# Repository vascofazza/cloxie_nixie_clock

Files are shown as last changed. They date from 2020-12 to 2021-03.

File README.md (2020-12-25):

# Cloxie

Schematics and code for Cloxie: my Nixie Tube Clock.




The circuit and custom PCB are designed around the popular IN-14 Nixie tubes.

You can find the schematics here: https://github.com/vascofazza/cloxie_nixie_clock/blob/main/nixie_board/schematics.pdf

Watch the clock in action: https://www.youtube.com/watch?v=ZD35oEGX9IY

## Features

- NTP time sync over Wi-Fi
- The tubes are dimmable via PWM
- 6 RGB leds under the tubes with configurable patterns
- Automatic brightness control with a photoresistor
- Configurable via an onboard web server (reachable on the local network at: http://cloxie.local)
- Configurable via a dedicated Android App (available here: https://github.com/vascofazza/Cloxie-connect)
- Optional temperature sensor
- Alarm/Timer/StopWatch functionalities

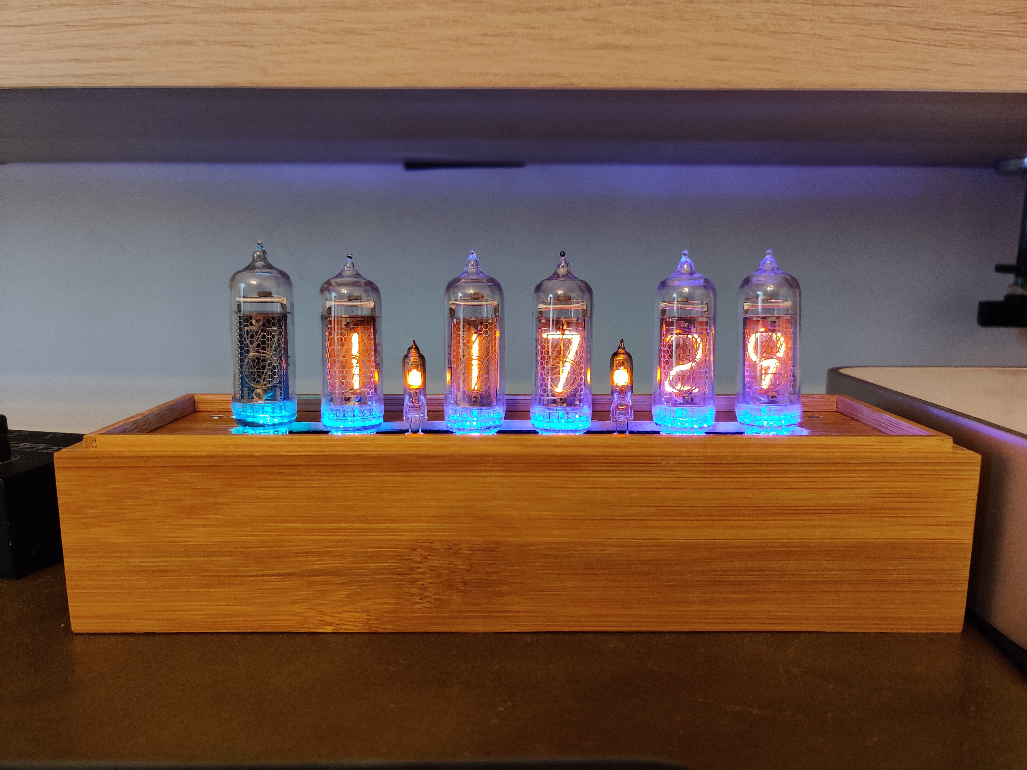
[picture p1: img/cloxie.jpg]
cloxie nixie clock


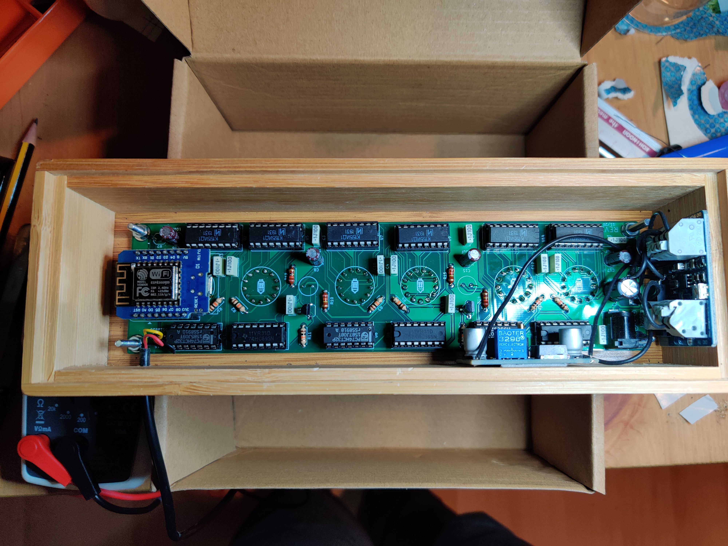
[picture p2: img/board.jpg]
cloxie board


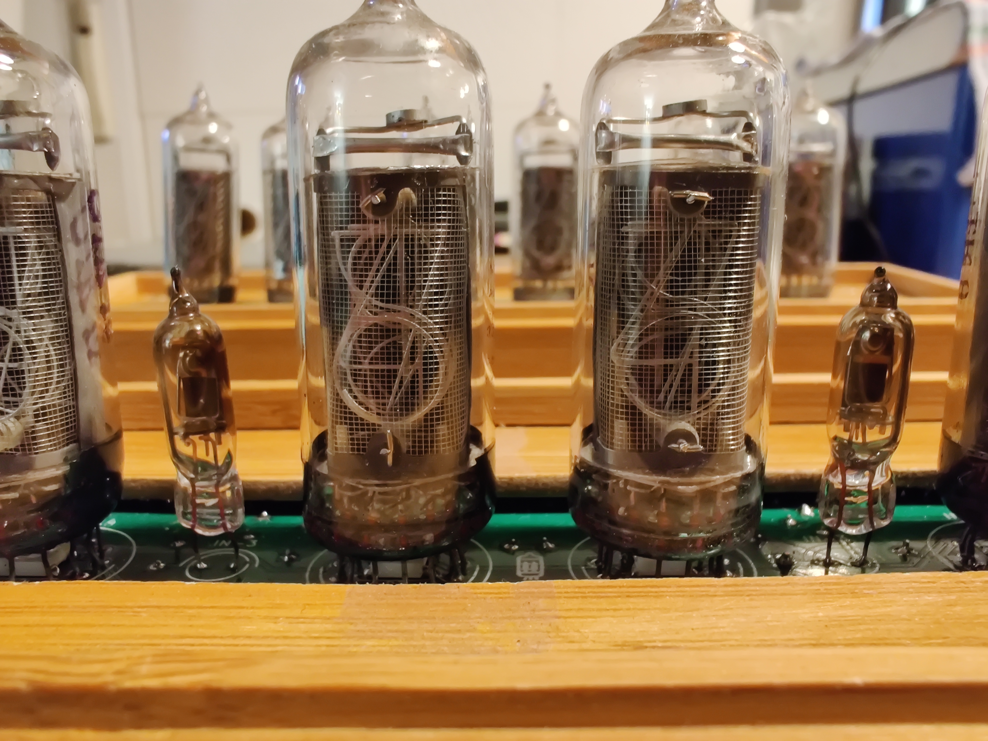
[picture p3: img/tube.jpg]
nixie tube


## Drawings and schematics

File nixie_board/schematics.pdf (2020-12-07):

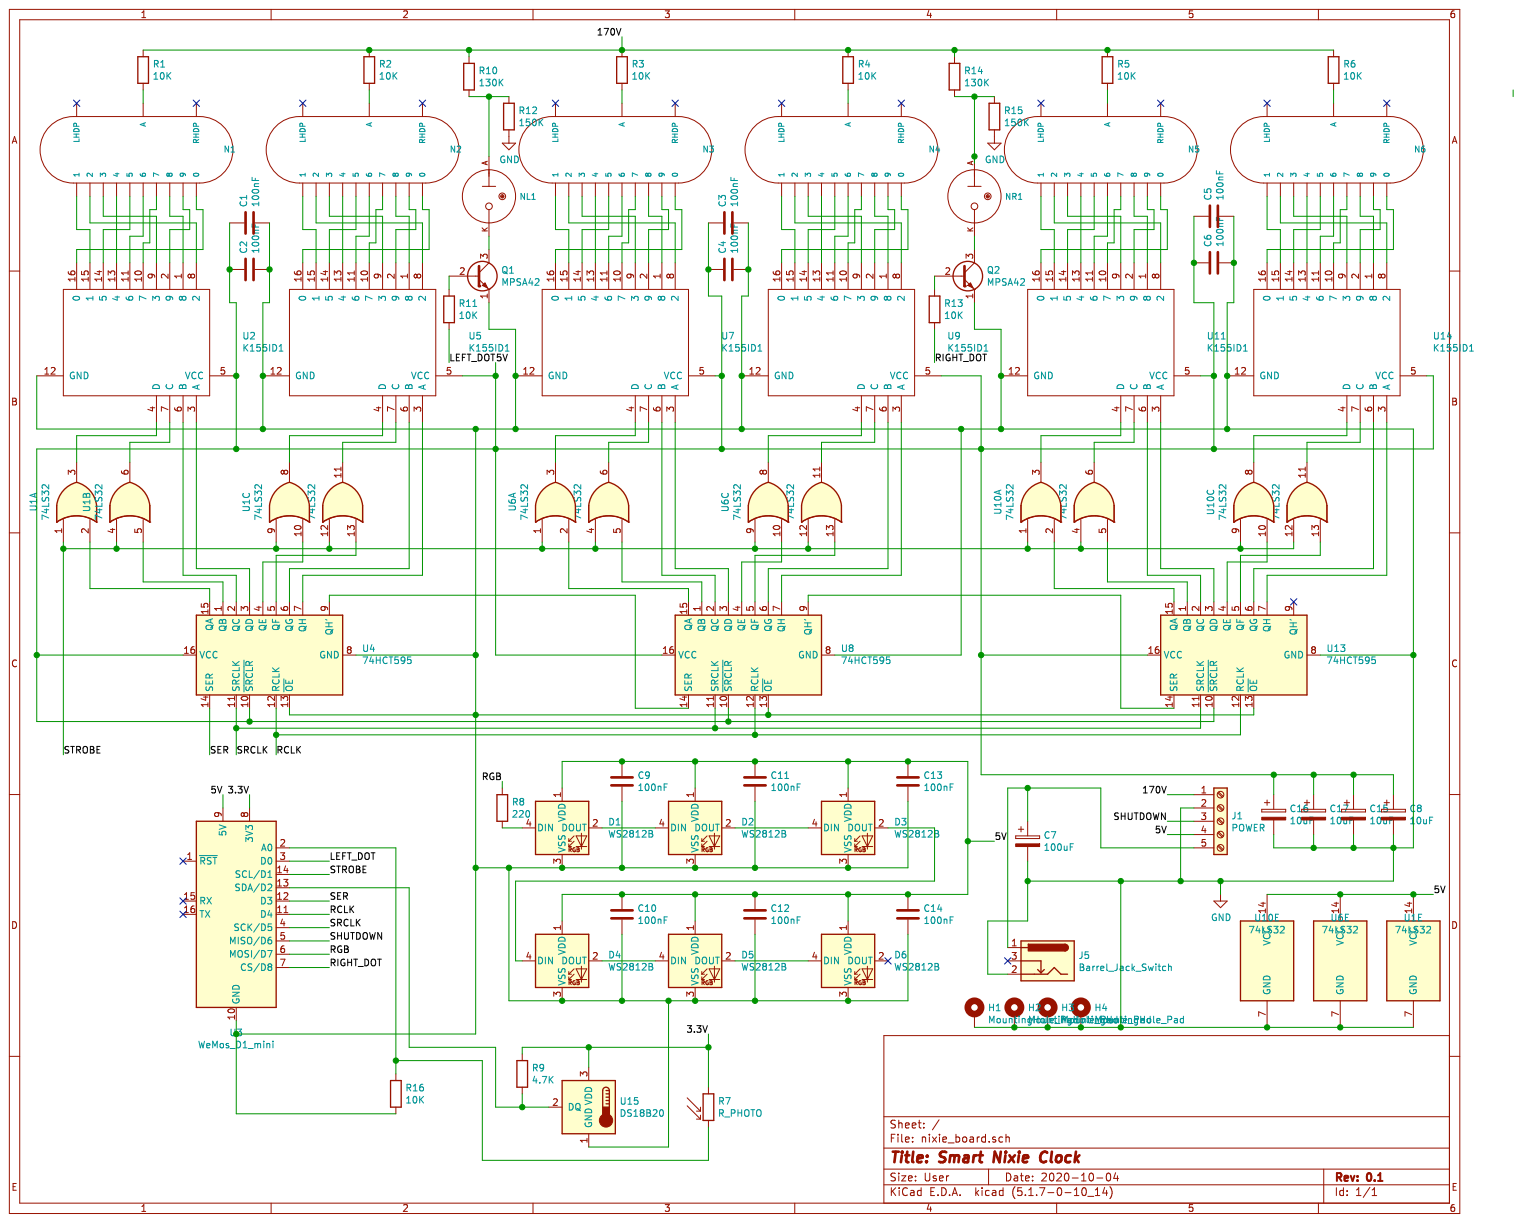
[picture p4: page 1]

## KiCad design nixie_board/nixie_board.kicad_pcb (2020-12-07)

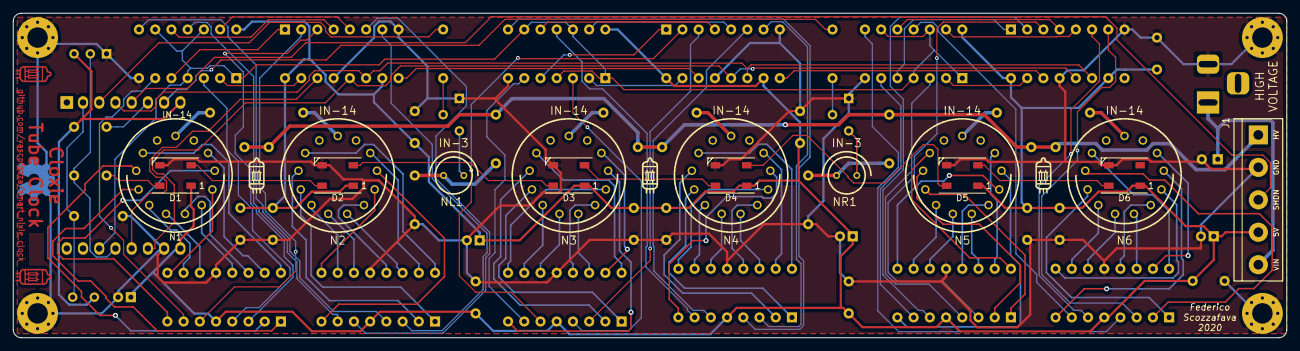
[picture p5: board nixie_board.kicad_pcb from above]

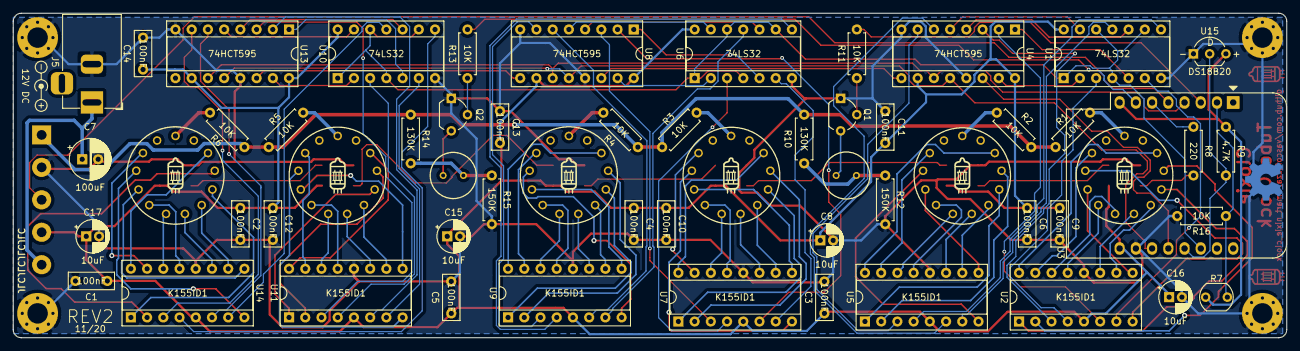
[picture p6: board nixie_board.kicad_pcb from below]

Board: 2 copper layers, 199.4 x 50.8 mm, 85 parts (59 on the bottom side), 131 nets.

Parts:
C1, C2, C3, C4, C5, C6, C9, C10, C11, C12, C13, C14: 100nF; C_Disc_D7.0mm_W2.5mm_P5.00mm
C7: 100uF; CP_Radial_D6.3mm_P2.50mm
C8, C15, C16, C17: 10uF; CP_Radial_D5.0mm_P2.00mm
D1, D2, D3, D4, D5, D6: WS2812B; LED_WS2812B_PLCC4_5.0x5.0mm_P3.2mm
H1, H2, H3, H4: MountingHole_Pad; MountingHole_3.2mm_M3_Pad_Via
J1: POWER; TerminalBlock_bornier-5_P5.08mm
J5: Barrel_Jack_Switch; BarrelJack_Horizontal
N1, N2, N3, N4, N5, N6: IN-14; nixies-us-IN-14
NL1: IN-3; nixies-us-IN-3
NR1: IN-3; nixies-us-IN-3
Q1, Q2: MPSA42; TO-92_Wide
R1, R2, R3, R4, R5, R6, R11, R13, R16: 10K; R_Axial_DIN0207_L6.3mm_D2.5mm_P7.62mm_Horizontal
R7: R_PHOTO; R_LDR_5.1x4.3mm_P3.4mm_Vertical
R8: 220; R_Axial_DIN0207_L6.3mm_D2.5mm_P7.62mm_Horizontal
R9: 4.7K; R_Axial_DIN0207_L6.3mm_D2.5mm_P7.62mm_Horizontal
R10, R14: 130K; R_Axial_DIN0207_L6.3mm_D2.5mm_P7.62mm_Horizontal
R12, R15: 150K; R_Axial_DIN0207_L6.3mm_D2.5mm_P7.62mm_Horizontal
S1: Symbol_Barrel_Polarity
S2, S2b: OSHW-Symbol_6.7x6mm_Copper
S4, S5: LOGO; tube
S6, S7, S8, S9, S10, S11, S12, S13, S15, S16, S17: LOGO; tube_silk
U1, U6, U10: 74LS32; DIP-14_W7.62mm_Socket
U2, U5, U7, U9, U11, U14: K155ID1; DIP-16_W7.62mm_Socket
U3: WeMos_D1_mini; WEMOS_D1_mini_light
U4, U8, U13: 74HCT595; DIP-16_W7.62mm_Socket
U15: DS18B20; TO-92_Inline_Wide

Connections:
/3.3V: R7.1, R9.1, U3.8, U15.3
/5V: C1.1, C2.1, C3.1, C4.1, C5.1, C6.1, C8.1, C9.1, C10.1, C11.1, C12.1, C13.1, C14.1, C15.1, C16.1, C17.1, D1.1, D2.1, D3.1, D4.1, D5.1, D6.1, J1.4, U1.14, U2.5, U3.9, U4.10, U4.16, U5.5, U6.14, U7.5, U8.10, U8.16, U9.5, U10.14, U11.5, U13.10, U13.16, U14.5
/170V: J1.1, R1.1, R2.1, R3.1, R4.1, R5.1, R6.1, R10.1, R14.1
/LEFT_DOT: R11.2, U3.3
/RCLK: U3.11, U4.12, U8.12, U13.12
/RGB: R8.1, U3.6
/RIGHT_DOT: R13.2, U3.7
/SER: U3.12, U4.14
/SHUTDOWN: J1.3, U3.5
/SRCLK: U3.4, U4.11, U8.11, U13.11
/STROBE: U1.1, U1.4, U1.9, U1.12, U3.14, U6.1, U6.4, U6.9, U6.12, U10.1, U10.4, U10.9, U10.12
GND: C1.2, C2.2, C3.2, C4.2, C5.2, C6.2, C7.2, C8.2, C9.2, C10.2, C11.2, C12.2, C13.2, C14.2, C15.2, C16.2, C17.2, D1.3, D2.3, D3.3, D4.3, D5.3, D6.3, H1.1, H2.1, H3.1, H4.1, J1.2, J5.2, Q1.1, Q2.1, R12.2, R15.2, R16.2, U1.7, U2.12, U3.10, U4.8, U4.13, U5.12, U6.7, U7.12, U8.8, U8.13, U9.12, U10.7, U11.12, U13.8, U13.13, U14.12, U15.1
unnamed: C7.1, J1.5, J5.1
unnamed: D1.2, D2.4
unnamed: D1.4, R8.2
unnamed: D2.2, D3.4
unnamed: D3.2, D4.4
unnamed: D4.2, D5.4
unnamed: D5.2, D6.4
unnamed: N1.0, U2.16
unnamed: N1.1, U2.15
unnamed: N1.2, U2.8
unnamed: N1.3, U2.9
unnamed: N1.4, U2.13
unnamed: N1.5, U2.14
unnamed: N1.6, U2.11
unnamed: N1.7, U2.10
unnamed: N1.8, U2.1
unnamed: N1.9, U2.2
unnamed: N1.A, R1.2
unnamed: N2.0, U5.16
unnamed: N2.1, U5.15
unnamed: N2.2, U5.8
unnamed: N2.3, U5.9
unnamed: N2.4, U5.13
unnamed: N2.5, U5.14
unnamed: N2.6, U5.11
unnamed: N2.7, U5.10
unnamed: N2.8, U5.1
unnamed: N2.9, U5.2
unnamed: N2.A, R2.2
unnamed: N3.0, U7.16
unnamed: N3.1, U7.15
unnamed: N3.2, U7.8
unnamed: N3.3, U7.9
unnamed: N3.4, U7.13
unnamed: N3.5, U7.14
unnamed: N3.6, U7.11
unnamed: N3.7, U7.10
unnamed: N3.8, U7.1
unnamed: N3.9, U7.2
unnamed: N3.A, R3.2
unnamed: N4.0, U9.16
unnamed: N4.1, U9.15
unnamed: N4.2, U9.8
unnamed: N4.3, U9.9
unnamed: N4.4, U9.13
unnamed: N4.5, U9.14
unnamed: N4.6, U9.11
unnamed: N4.7, U9.10
unnamed: N4.8, U9.1
unnamed: N4.9, U9.2
unnamed: N4.A, R4.2
unnamed: N5.0, U11.16
unnamed: N5.1, U11.15
unnamed: N5.2, U11.8
unnamed: N5.3, U11.9
unnamed: N5.4, U11.13
unnamed: N5.5, U11.14
unnamed: N5.6, U11.11
unnamed: N5.7, U11.10
unnamed: N5.8, U11.1
unnamed: N5.9, U11.2
unnamed: N5.A, R5.2
unnamed: N6.0, U14.16
unnamed: N6.1, U14.15
unnamed: N6.2, U14.8
unnamed: N6.3, U14.9
unnamed: N6.4, U14.13
unnamed: N6.5, U14.14
unnamed: N6.6, U14.11
unnamed: N6.7, U14.10
unnamed: N6.8, U14.1
unnamed: N6.9, U14.2
unnamed: N6.A, R6.2
unnamed: NL1.A, R10.2, R12.1
unnamed: NL1.K, Q1.3
unnamed: NR1.A, R14.2, R15.1
unnamed: NR1.K, Q2.3
unnamed: Q1.2, R11.1
unnamed: Q2.2, R13.1
unnamed: R9.2, U3.13, U15.2
unnamed: R7.2, R16.1, U3.2
unnamed: U1.2, U4.15
unnamed: U1.3, U2.4
unnamed: U1.5, U4.1
unnamed: U1.6, U2.7
unnamed: U1.8, U5.4
unnamed: U1.10, U4.4
unnamed: U1.11, U5.7
unnamed: U1.13, U4.5
unnamed: U2.3, U4.3
unnamed: U2.6, U4.2
unnamed: U4.6, U5.6
unnamed: U4.7, U5.3
unnamed: U4.9, U8.14
unnamed: U6.2, U8.15
unnamed: U6.3, U7.4
unnamed: U6.5, U8.1
unnamed: U6.6, U7.7
unnamed: U6.8, U9.4
unnamed: U6.10, U8.4
unnamed: U6.11, U9.7
unnamed: U6.13, U8.5
unnamed: U7.3, U8.3
unnamed: U7.6, U8.2
unnamed: U8.6, U9.6
unnamed: U8.7, U9.3
unnamed: U10.2, U13.15
unnamed: U10.3, U11.4
unnamed: U10.5, U13.1
unnamed: U10.6, U11.7
unnamed: U10.8, U14.4
unnamed: U10.10, U13.4
unnamed: U10.11, U14.7
unnamed: U10.13, U13.5
unnamed: U11.3, U13.3
unnamed: U11.6, U13.2
unnamed: U13.6, U14.6
unnamed: U13.7, U14.3
unnamed: U8.9, U13.14

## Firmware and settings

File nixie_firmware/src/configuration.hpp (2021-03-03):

#ifndef CONFIGURATION_HPP
#define CONFIGURATION_HPP

#include <Arduino.h>
#include <EEPROM.h>
#include "utils.hpp"

#define FIRMWARE_VERSION PSTR("1.4.4")

//#define DEBUG

#ifdef DEBUG
#define DEBUG_PRINT(x) Serial.print(x)
#define DEBUG_PRINTLN(x) Serial.println(x)
#define DEBUG_PRINTF(x, y) Serial.printf(x, y)
#else
#define DEBUG_PRINT(x)
#define DEBUG_PRINTLN(x)
#define DEBUG_PRINTF(x, y)
#endif

//CLOCK
#define CLOCK_CYCLE (1800 * 1000) //30m
#define DATE_CYCLE (60 * 1000)    //60s
#define TEMP_CYCLE (60 * 1000)    //60s
#define TIMER_CYCLE (60 * 1000)   //60s
#define STOPWATCH_CYCLE (60 * 1000)   //60s

//WIFI
#define HOST_NAME PSTR("cloxie")
#define WIFI_SSID PSTR("Cloxie")
#define WIFI_PASSWORD PSTR("cloxieclock")
#define PORTAL_TIMEOUT 600        //in seconds
#define WIFI_RECONNECT_DELAY 300  //5 mins
#define WIFI_RECONNECT_ATTEMPTS 6 //before a full reset

//TUBES
#define MIN_TUBE_BRIGHTNESS 80
#define MAX_TUBE_BRIGHNTESS 700
#define MAX_DOT_BRIGHNTESS 1000
#define BRIGTHNESS_REFRESH 100
#define CATHODE_POISONING_PREVENTION_TIME (60 * 5 * 1000)         //5m
#define CATHODE_POISONING_TRIGGER_TIME (60 * 60 + 30 * 60) * 1000 //1h30m0s

//LEDS
#define NUM_LEDS 6
#define FRAMES_PER_SECOND 30
#define PATTERN_DELAY 600000 //10 mins
#define HUE_DELAY 250
#define MIN_LED_BRIGHTNESS 10
#define MAX_LED_BRIGHNTESS 100
#define LED_STATIC_HUE_VALUE 19
#define LED_SHUTDOWN_THRESHOLD 40

//SENSORS
#define NUM_OF_READINGS 200
#define ANALOG_READ_INTERVAL 50
#define TEMP_READ_INTERVAL 1000
#define MAX_LIGHT_READING_VAL 900

//MISC
#define DEFAULT_BRIGHTNESS PWMRANGE / 2
#define TRANSITION_TIME (10 * 1000) //10s
#define TURN_ON_OFF_TIME (5 * 1000) //5s
#define MAGIC_NUMBER 42
#define ARRAY_SIZE(A) (sizeof(A) / sizeof((A)[0]))

//GITHUB
#define GHOTA_DO_NOT_USE_ARDUINO_JSON
#define GHOTA_USER PSTR("vascofazza")
#define GHOTA_REPO PSTR("cloxie_nixie_clock")
#define GHOTA_CURRENT_TAG FIRMWARE_VERSION
#define GHOTA_BIN_FILE PSTR("cloxie_d1_mini.bin")
#define GHOTA_ACCEPT_PRERELEASE 0
#define GHOTA_INTERVAL (3600 * 6 * 1000) //6h

struct Config
{
  int timezone;
  bool h24;
  bool leds;
  bool celsius;
  int led_configuration;
  bool adaptive_brightness;
  int brightness_offset;       // light sensor offset
  int shutdown_threshold;      // light sensor threshold for turning off the tubes
  unsigned int shutdown_delay; // seconds before shutdown
  int blink_mode;
  int sleep_hour;
  int wake_hour;
  bool termometer;
  bool date;
  unsigned int depoisoning;
  unsigned int clock_cycle;
  char timezone_name[30];
  char version[6];
  unsigned int slot_duration;
  unsigned int led_off_threshold;
  unsigned int min_tube_brightness;
  unsigned int max_tube_brightness;
  unsigned int min_led_brightness;
  unsigned int max_led_brightness;
};

extern Config config;

void printParams();

void check_params();

void setup_configuration();

void save_configuration();

#endif

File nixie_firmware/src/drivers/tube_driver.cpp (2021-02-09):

#include "tube_driver.hpp"

TubeDriver::TubeDriver(SensorDriver *sensor_driver)
{
  this->sensor_driver = sensor_driver;
  status = false;
  int_status = false;
  brightness = config.min_tube_brightness;
  l_dot_brightness = 0;
  r_dot_brightness = 0;

  pinMode(STROBE, OUTPUT);
  pinMode(LEFT_DOT, OUTPUT);
  pinMode(RIGHT_DOT, OUTPUT);
  pinMode(SHF_LATCH, OUTPUT);
  pinMode(SHF_CLOCK, OUTPUT);
  pinMode(SHF_DATA, OUTPUT);
  pinMode(SHUTDOWN_PIN, INPUT);
  cathode_poisoning_cycle.Every(config.depoisoning, std::bind(&TubeDriver::cathode_poisoning_prevention, this, CATHODE_POISONING_PREVENTION_TIME));
  run_test();
  set_tubes(0, 0, 0, 0, 0, 0);
  turn_off(false);
  shutdown();
  tube_ticker.attach_ms(BRIGTHNESS_REFRESH, std::bind(&TubeDriver::adjust_brightness, this));
}

void TubeDriver::run_test()
{
  DEBUG_PRINT(F("Running tube tests..."));

  set_tube_brightness(PWMRANGE, PWMRANGE, PWMRANGE);
  for (int i = 0; i < 10; i++)
  {
    set_tubes(i, i, i, i, i, i);
    for (int b = 0; b < 1024; b += 100)
    {
      set_tube_brightness(b, b, b);
      activeDelay(25);
    }
    for (int b = 1024; b >= 0; b -= 100)
    {
      set_tube_brightness(b, b, b);
      activeDelay(25);
    }
  }
  set_tube_brightness(0, 0, 0);
  DEBUG_PRINTLN(F("Done!"));
}

/*
   -1 or digits > 9 turns off the nixie tube
*/
void TubeDriver::set_tubes(int8_t h, int8_t hh, int8_t m, int8_t mm, int8_t s, int8_t ss)
{
  static int8_t prev_h = -1;
  static int8_t prev_hh = -1;
  static int8_t prev_m = -1;
  static int8_t prev_mm = -1;
  static int8_t prev_s = -1;
  static int8_t prev_ss = -1;

  if (h == prev_h && hh == prev_hh && m == prev_m && mm == prev_mm && s == prev_s && ss == prev_ss)
    return;

  prev_h = h;
  prev_hh = hh;
  prev_m = m;
  prev_mm = mm;
  prev_s = s;
  prev_ss = ss;

  if (h >= 0)
  {
    if (h == 0)
      h = 1;
    else if (h == 1)
      h = 0;
    else
      h = (11 - h);
  }
  if (hh >= 0)
  {
    if (hh == 0)
      hh = 1;
    else if (hh == 1)
      hh = 0;
    else
      hh = (11 - hh);
  }
  if (m >= 0)
  {
    if (m == 0)
      m = 1;
    else if (m == 1)
      m = 0;
    else
      m = (11 - m);
  }
  if (mm >= 0)
  {
    if (mm == 0)
      mm = 1;
    else if (mm == 1)
      mm = 0;
    else
      mm = (11 - mm);
  }
  if (s >= 0)
  {
    if (s == 0)
      s = 1;
    else if (s == 1)
      s = 0;
    else
      s = (11 - s);
  }
  if (ss >= 0)
  {
    if (ss == 0)
      ss = 1;
    else if (ss == 1)
      ss = 0;
    else
      ss = (11 - ss);
  }

  //prepare the data payload
  unsigned int payload = (ss & 0xF) | ((s & 0xF) << 4) | ((mm & 0xF) << 8) | ((m & 0xF) << 12) | ((hh & 0xF) << 16) | ((h & 0xF) << 20);
  // the LEDs don't change while you're sending in bits:

  noInterrupts();
  digitalWrite(SHF_LATCH, LOW);
  // shift out the bits:
  shiftOut(SHF_DATA, SHF_CLOCK, LSBFIRST, payload);
  shiftOut(SHF_DATA, SHF_CLOCK, LSBFIRST, payload >> 8);
  shiftOut(SHF_DATA, SHF_CLOCK, LSBFIRST, payload >> 16);
  //take the latch pin high so the LEDs will light up:
  digitalWrite(SHF_LATCH, HIGH);
  interrupts();
}

void TubeDriver::adjust_brightness()
{
  if (!int_status)
    return;
  set_brightness(sensor_driver->get_light_sensor_reading());
}

void TubeDriver::loop()
{
  if (config.depoisoning > 0)
    cathode_poisoning_cycle.Update();
  else
  {
    cathode_poisoning_cycle.Stop();
  }
}

void TubeDriver::display_time_and_date(int8_t h, int8_t m, int8_t s, bool show_zeros)
{
  int8_t hour1 = h / 10; //handle 10/24h and tube off on 0
  int8_t hour2 = h % 10;
  if (hour1 == 0 && hour2 != 0 && !show_zeros)
    hour1 = -1;

  int8_t min1 = m / 10;
  int8_t min2 = m % 10;
  int8_t sec1 = s / 10;
  int8_t sec2 = s % 10;

  set_tubes(hour1, hour2, min1, min2, sec1, sec2);
}

void TubeDriver::display_temperature(float temp)
{
  int integer = (int)temp;
  int decimal = (temp - integer) * 100;
  int i1 = integer / 10;
  int i2 = integer % 10;
  int d1 = decimal / 10;
  int d2 = decimal % 10;

  set_tubes(-1, -1, i1, i2, d1, d2);
  set_dots_brightness(0, PWMRANGE);
}

void TubeDriver::set_tube_brightness(int16_t brightness, int16_t l_dot_brightness, int16_t r_dot_brightness)
{
#ifdef DEBUG
  static elapsedMillis deb_mils;
  if (deb_mils > 1000)
  {
    DEBUG_PRINT(F("Tube brightness: "));
    DEBUG_PRINTLN(brightness);
    deb_mils = 0;
  }
#endif
  analogWrite(STROBE, PWMRANGE - brightness);
  analogWrite(LEFT_DOT, l_dot_brightness);
  analogWrite(RIGHT_DOT, r_dot_brightness);
}

int scale(int val)
{
  float log_scale = 2 - 2 / (1 + (val / (float)PWMRANGE));
  val = log_scale * PWMRANGE;
  return max(val, (int)config.min_tube_brightness);
}

void TubeDriver::set_brightness(int16_t brightness)
{
  if (!status)
    return;
  this->brightness = brightness <= (int16_t)config.min_tube_brightness ? this->brightness : scale(brightness);
  int dot_brightness = map(this->brightness, 0, PWMRANGE, 0, MAX_DOT_BRIGHNTESS);
  int left = map(l_dot_brightness, 0, PWMRANGE, 0, dot_brightness);
  int right = map(r_dot_brightness, 0, PWMRANGE, 0, dot_brightness);
  brightness = map(this->brightness, config.min_tube_brightness, PWMRANGE, config.min_tube_brightness, config.max_tube_brightness);
  set_tube_brightness(brightness, left, right);
}

void TubeDriver::set_dots_brightness(int16_t left, int16_t right)
{
  l_dot_brightness = left;
  r_dot_brightness = right;
}

void TubeDriver::shutdown()
{
  pinMode(SHUTDOWN_PIN, OUTPUT);
  digitalWrite(SHUTDOWN_PIN, HIGH);
}

void TubeDriver::turn_off(bool fade)
{
  if (!status)
    return;
  if (fade)
  {
    int_status = false;
    for (int i = brightness; i >= 0; i--)
    {
      set_tube_brightness(i, i, i);
      delay(TURN_ON_OFF_TIME / (brightness + 1));
    }
    int_status = true;
  }
  digitalWrite(STROBE, HIGH);
  digitalWrite(LEFT_DOT, LOW);
  digitalWrite(RIGHT_DOT, LOW);
  status = false;
}

void TubeDriver::turn_on(bool fade)
{
  if (status)
    return;
  status = true;
  pinMode(SHUTDOWN_PIN, INPUT);
  if (fade)
  {
    int_status = false;
    for (int i = 0; i <= scale(max(sensor_driver->get_light_sensor_reading(), (float)config.min_tube_brightness)); i++)
    {
      set_tube_brightness(i, i, i);
      delay(TURN_ON_OFF_TIME / sensor_driver->get_light_sensor_reading());
    }
    int_status = true;
  }
  else
  {
    set_brightness(-1);
  }
}

bool TubeDriver::get_status()
{
  return status;
}
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

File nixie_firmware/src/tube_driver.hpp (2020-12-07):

#ifndef TUBE_DRIVER_HPP
#define TUBE_DRIVER_HPP

#include <elapsedMillis.h>
#include <EveryTimer.h>
#include "configuration.hpp"
#include "sensors.hpp"
#include "utils.hpp"
#include <Ticker.h>

#define LEFT_DOT D0
#define RIGHT_DOT D8
#define STROBE D1
#define SHF_LATCH D4
#define SHF_CLOCK D5
#define SHF_DATA D3
#define SHUTDOWN_PIN D6

class TubeDriver
{
private:
    int16_t brightness;
    int16_t l_dot_brightness;
    int16_t r_dot_brightness;
    bool status;
    bool int_status;
    Ticker tube_ticker;
    EveryTimer cathode_poisoning_cycle;
    SensorDriver *sensor_driver;
    void adjust_brightness();
    void set_tube_brightness(int16_t, int16_t, int16_t);

public:
    TubeDriver(SensorDriver *);

    void run_test();

    void loop();

    void set_tubes(int8_t, int8_t, int8_t, int8_t, int8_t, int8_t);

    void set_brightness(int16_t);

    void set_dots_brightness(int16_t, int16_t);

    void display_time_and_date(int8_t, int8_t, int8_t, bool);

    void display_temperature(float);

    void shutdown();

    void turn_off(bool);

    void turn_on(bool);

    bool get_status();

    void cathode_poisoning_prevention(unsigned long);
};

#endif

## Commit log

2020-10-04 rev 0.1
    [nixie_board.kicad_pcb, nixie_board.sch]
2020-10-06 schematic revision + first PCB
    [nixie_board.kicad_pcb, nixie_board.sch]
2020-10-06 rev 0.2
    [nixie_board.kicad_pcb, nixie_board.sch]
2020-10-06 clearence review
    [nixie_board.kicad_pcb]
2020-10-08 board review 3
    [nixie_board.kicad_pcb, nixie_board.sch]
2020-10-12 final board review
    [nixie_board-B_Cu.gbr, nixie_board-B_Mask.gbr, nixie_board-B_SilkS.gbr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]
2020-10-12 PCB version 2
    [nixie_board-B_Cu.gbr, nixie_board-B_Mask.gbr, nixie_board-B_SilkS.gbr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]
2020-10-14 huge step forward
    [configuration.h]
2020-10-14 PROGMEM + typo fix
    [configuration.h]
2020-10-15 name update
    [configuration.h]
2020-10-15 handling more parameters
    [configuration.h]
2020-10-17 pcb measurements
    [nixie_board.kicad_pcb]
2020-11-01 massive update + migration to platformIO + v2 HW preparation
    [configuration.h, nixie_board.kicad_pcb, nixie_board.sch]
2020-11-01 refactoring + timer implementation
2020-11-02 timer fix
2020-11-05 led patterns, led modes, dynamic shutdown, bugfixes
    [nixie_board.sch]
2020-11-06 pcb REV1
    [nixie_board.kicad_pcb, nixie_board.sch]
2020-11-06 wifi connection and reset update
    [configuration.hpp, tube_driver.cpp]
2020-11-11 board rev2
    [nixie_board.kicad_pcb, nixie_board.sch]
2020-11-15 led and sensors async update
2020-11-16 shutdown high impedance fix
    [tube_driver.cpp]
2020-11-16 rev2 board fix
    [nixie_board.kicad_pcb]
2020-12-07 rev2 board
    [nixie_board-B_Cu.gbr, nixie_board-B_Mask.gbr, nixie_board-B_SilkS.gbr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]
2020-12-07 pdf schematics
    [nixie_board-B_Cu.gbr, nixie_board-B_Mask.gbr, nixie_board-B_SilkS.gbr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]
2020-12-08 device status request
2020-12-23 remote timer control
2021-01-04 wifi reconnect stability improvement
    [configuration.hpp]
2021-01-04 new led patterns
2021-01-04 automatic calibration routine
2021-01-04 calibration fix
2021-01-07 led patterns bugfixes
2021-01-07 timer patterns
2021-02-09 remove sensor pre-feed
